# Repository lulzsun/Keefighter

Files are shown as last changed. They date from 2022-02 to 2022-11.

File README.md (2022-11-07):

# Keefighter
Keyboard-styled gamepad controller designed for fighting games. Made to fit into 60% keyboard cases.

## License


The Keefighter controller is licensed under [Creative Commons Attribution-NonCommercial 4.0 International License](https://creativecommons.org/licenses/by-nc/4.0).

This PCB design may be freely reproduced, modified, and manufactured for personal use only. If you would like to use this design commercially please reach out to request permission.

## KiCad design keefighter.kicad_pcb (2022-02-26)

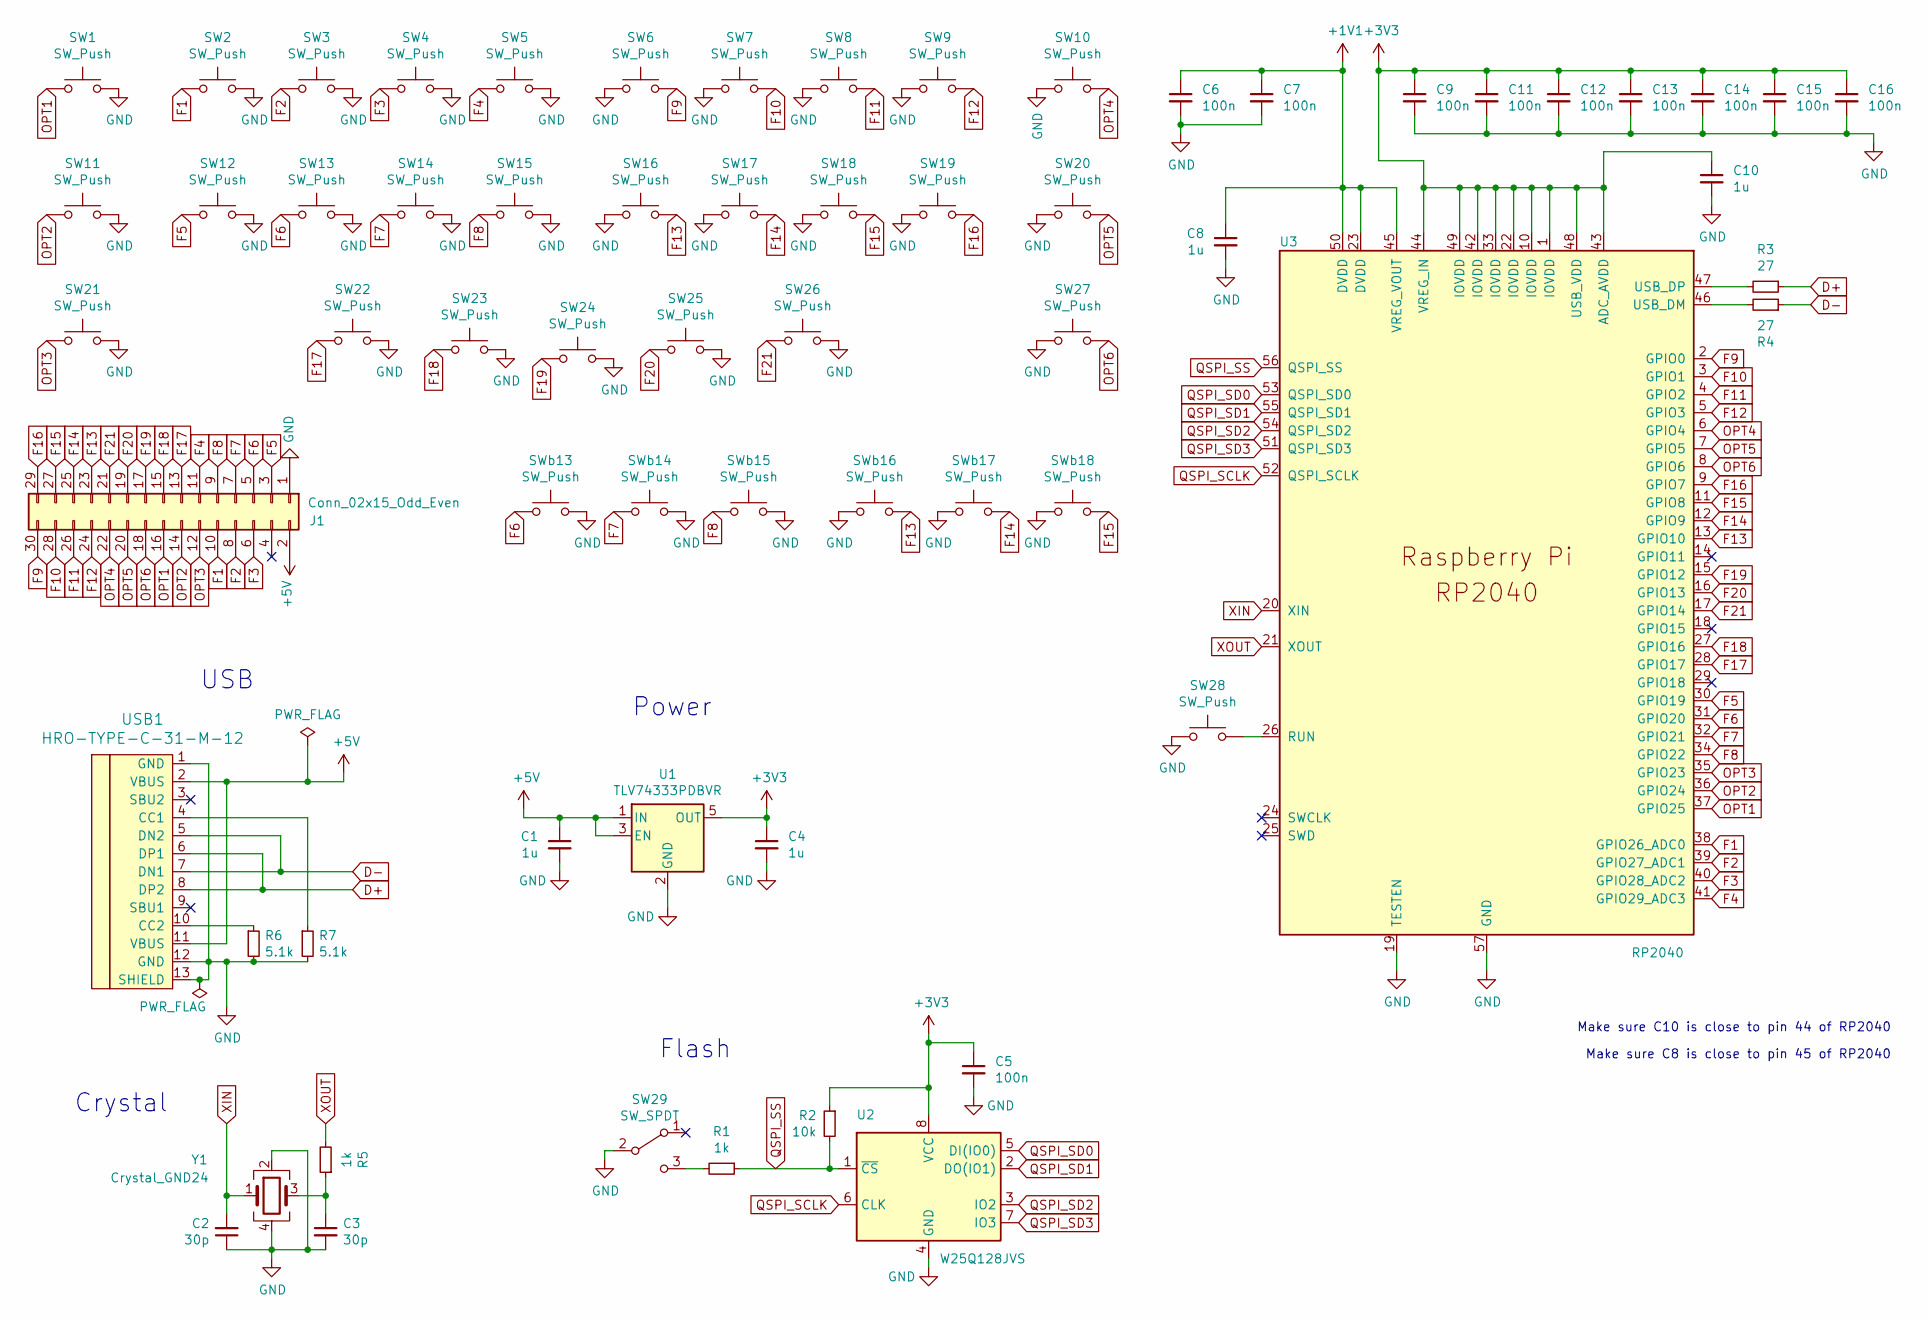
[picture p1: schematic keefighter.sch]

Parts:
C1, C4, C8, C10: 1u; C_0603_1608Metric; LCSC C15849
C2, C3: 30p; C_0603_1608Metric; LCSC C22397
C5, C6, C7, C9, C11, C12, C13, C14, C15, C16: 100n; C_0603_1608Metric; LCSC C14663
J1: Conn_02x15_Odd_Even; PinHeader_2x15_P2.54mm_Vertical
R1, R5: 1k; R_0603_1608Metric; LCSC C21190
R2: 10k; R_0603_1608Metric; LCSC C25804
R3, R4: 27; R_0603_1608Metric; LCSC C25190
R6, R7: 5.1k; R_0603_1608Metric; LCSC C23186
SW1, SW2, SW3, SW4, SW5, SW6, SW7, SW8, SW9, SW10, SW11, SW12, SW13, SW14, SW15, SW16, SW17, SW18, SW19, SW20, SW21, SW22, SW23, SW24, SW25, SW26, SW27: SW_Push; Kailh_socket_PG1350
SW28: SW_Push; SW_Push_SPST_NO_Alps_SKRK; LCSC C115357
SW29: SW_SPDT; SW_SPDT_PCM12; LCSC C431541
SWb13, SWb14, SWb15, SWb16, SWb17, SWb18: SW_Push; Kailh_socket_PG1350
U1: TLV74333PDBVR; SOT-23-5; LCSC C408972
U2: W25Q128JVS; SOIC-8_5.23x5.23mm_P1.27mm; LCSC C97521
U3: RP2040; RP2040-QFN-56; LCSC C2040
USB1: HRO-TYPE-C-31-M-12; HRO-TYPE-C-31-M-12-Assembly; LCSC C165948
Y1: Crystal_GND24; Crystal_SMD_3225-4Pin_3.2x2.5mm; LCSC C9002

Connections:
+1V1: C6.1, C7.1, C8.1, U3.23 (DVDD), U3.45 (VREG_VOUT), U3.50 (DVDD)
+3V3: C4.1, C5.1, C9.1, C10.1, C11.1, C12.1, C13.1, C14.1, C15.1, C16.1, R2.1, U1.5 (OUT), U2.8 (VCC), U3.1 (IOVDD), U3.10 (IOVDD), U3.22 (IOVDD), U3.33 (IOVDD), U3.42 (IOVDD), U3.43 (ADC_AVDD), U3.44 (VREG_IN), U3.48 (USB_VDD), U3.49 (IOVDD)
+5V: C1.1, J1.2, U1.1 (IN), U1.3 (EN), USB1.2 (VBUS), USB1.11 (VBUS)
D+: R3.1, USB1.6 (DP1), USB1.8 (DP2)
D-: R4.1, USB1.5 (DN2), USB1.7 (DN1)
F1: J1.10, SW2.1, U3.38 (GPIO26_ADC0)
F2: J1.8, SW3.1, U3.39 (GPIO27_ADC1)
F3: J1.6, SW4.1, U3.40 (GPIO28_ADC2)
F4: J1.11, SW5.1, U3.41 (GPIO29_ADC3)
F5: J1.3, SW12.1, U3.30 (GPIO19)
F6: J1.5, SW13.1, SWb13.1, U3.31 (GPIO20)
F7: J1.7, SW14.1, SWb14.1, U3.32 (GPIO21)
F8: J1.9, SW15.1, SWb15.1, U3.34 (GPIO22)
F9: J1.30, SW6.2, U3.2 (GPIO0)
F10: J1.28, SW7.2, U3.3 (GPIO1)
F11: J1.26, SW8.2, U3.4 (GPIO2)
F12: J1.24, SW9.2, U3.5 (GPIO3)
F13: J1.23, SW16.2, SWb16.2, U3.13 (GPIO10)
F14: J1.25, SW17.2, SWb17.2, U3.12 (GPIO9)
F15: J1.27, SW18.2, SWb18.2, U3.11 (GPIO8)
F16: J1.29, SW19.2, U3.9 (GPIO7)
F17: J1.13, SW22.1, U3.28 (GPIO17)
F18: J1.15, SW23.1, U3.27 (GPIO16)
F19: J1.17, SW24.1, U3.15 (GPIO12)
F20: J1.19, SW25.1, U3.16 (GPIO13)
F21: J1.21, SW26.1, U3.17 (GPIO14)
GND: C1.2, C2.1, C3.2, C4.2, C5.2, C6.2, C7.2, C8.2, C9.2, C10.2, C11.2, C12.2, C13.2, C14.2, C15.2, C16.2, J1.1, R6.2, R7.2, SW1.2, SW2.2, SW3.2, SW4.2, SW5.2, SW6.1, SW7.1, SW8.1, SW9.1, SW10.1, SW11.2, SW12.2, SW13.2, SW14.2, SW15.2, SW16.1, SW17.1, SW18.1, SW19.1, SW20.1, SW21.2, SW22.2, SW23.2, SW24.2, SW25.2, SW26.2, SW27.1, SW28.1, SW29.2 (B), SWb13.2, SWb14.2, SWb15.2, SWb16.1, SWb17.1, SWb18.1, U1.2 (GND), U2.4 (GND), U3.19 (TESTEN), U3.57 (GND), USB1.1 (GND), USB1.12 (GND), USB1.13 (SHIELD), Y1.2, Y1.4
unnamed: C3.1, R5.1, Y1.3
unnamed: R1.2, SW29.3 (C)
unnamed: R3.2, U3.47 (USB_DP)
unnamed: R4.2, U3.46 (USB_DM)
unnamed: R6.1, USB1.10 (CC2)
unnamed: R7.1, USB1.4 (CC1)
unnamed: SW28.2, U3.26 (RUN)
OPT1: J1.16, SW1.1, U3.37 (GPIO25)
OPT2: J1.14, SW11.1, U3.36 (GPIO24)
OPT3: J1.12, SW21.1, U3.35 (GPIO23)
OPT4: J1.22, SW10.2, U3.6 (GPIO4)
OPT5: J1.20, SW20.2, U3.7 (GPIO5)
OPT6: J1.18, SW27.2, U3.8 (GPIO6)
QSPI_SCLK: U2.6 (CLK), U3.52 (QSPI_SCLK)
QSPI_SD0: U2.5 (DI(IO0)), U3.53 (QSPI_SD0)
QSPI_SD1: U2.2 (DO(IO1)), U3.55 (QSPI_SD1)
QSPI_SD2: U2.3 (IO2), U3.54 (QSPI_SD2)
QSPI_SD3: U2.7 (IO3), U3.51 (QSPI_SD3)
QSPI_SS: R1.1, R2.2, U2.1 (~CS), U3.56 (QSPI_SS)
XIN: C2.2, U3.20 (XIN), Y1.1
XOUT: R5.2, U3.21 (XOUT)

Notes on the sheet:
Make sure C10 is close to pin 44 of RP2040
Crystal
Power
USB
Make sure C8 is close to pin 45 of RP2040
Flash

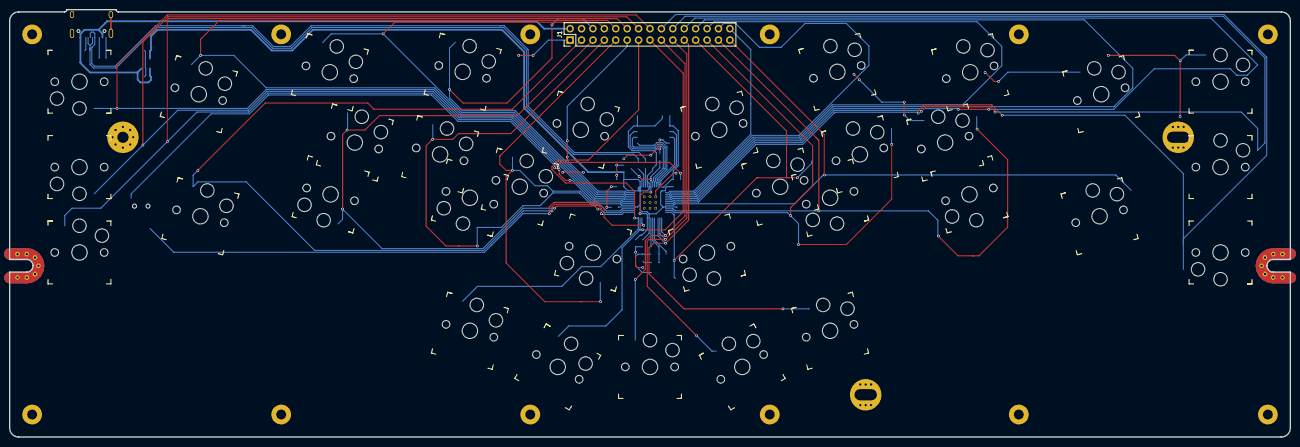
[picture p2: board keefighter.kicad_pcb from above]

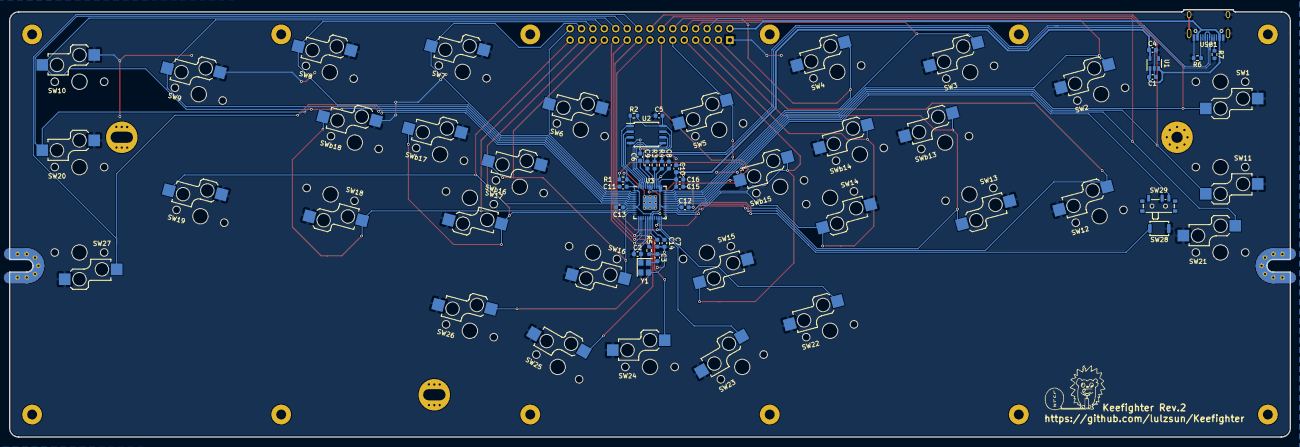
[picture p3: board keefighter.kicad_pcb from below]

Board: 2 copper layers, 285.0 x 95.1 mm, 65 parts (31 on the bottom side), 48 nets.

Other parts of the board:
Ref**: Val**; logo

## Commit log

2021-05-25 Local to remote commit
    [bottom foam.dxf, bottom panel.dxf, fusion pcb.dxf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]
2021-11-03 Fixed routing issues with matrix
    [keefighter.sch]
2022-01-25 Use components/schematics from flatbox
    jfedor2's flatbox will be used as a guide for building the Keefighter
    [keefighter.kicad_pcb, keefighter.sch]
2022-02-26 JLCPCB ready for prod
    [keefighter-B_Cu.gbl, keefighter-B_Mask.gbs, keefighter-B_Paste.gbp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]
